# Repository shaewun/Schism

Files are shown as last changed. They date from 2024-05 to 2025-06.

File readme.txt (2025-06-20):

Shield: [][cc-by-nc-sa]

This work is licensed under a
[Creative Commons Attribution-NonCommercial-ShareAlike 4.0 International License][cc-by-nc-sa].

[][cc-by-nc-sa]

[cc-by-nc-sa]: http://creativecommons.org/licenses/by-nc-sa/4.0/
[cc-by-nc-sa-image]: https://licensebuttons.net/l/by-nc-sa/4.0/88x31.png
[cc-by-nc-sa-shield]: https://img.shields.io/badge/License-CC%20BY--NC--SA%204.0-lightgrey.svg

Featured Components
-------------------
Kailh hot swap PCB modules
Raspberry Pi Pico
Gateron Clear Switches (35g)
Injection Molded Bjart Keycaps
USBC interconnected adjustable modules
USBC-GCC cable 

Construction
------------
The Schism utilizes 3 pieces of CNC cut and bent metal, assembled with stainless steel screws, nylon knobs, and nylon washers to protect your controllers finish.

The Modules utilize an open frame design, with a threaded bottom plate. Each module is secured in place using powerful neodymium magnets. This allows you to make adjustments on the fly, while not having to worry about your controller coming apart in transit or moving during the heat of battle!

Repairability
-------------
The controllers boards are sold as a set for replacement, and are open sourced. The modules themselves are also open source and made readily available for emergency replacement. Everything can be replaced with a SINGLE hex key :)

Functionality
-------------
The lowest possible latency and max compatibility is ensured in console and USB modes with the 133Mhz ARM Cortex processor found in the Raspberry Pi Pico.

Support for Gamecube, Switch, and PC are built in. Further console functionality can be enabled using a Brooks Wingman USB stick for consoles like PS4 and new Xboxes.

Guides for this Wingman functionality will be made available in the future, in the mean time feel free to reach out for support or reassurance in setting up additional console functionality, its very easy and straightforward. There are also members of the Discord who are always glad to help.

Ergonomic Benefits
------------------
The Schism represents a new generation of ergonomics for digital fight pad users.

Based on the b0xx layout by Hax$, the schism re-engineers the locations, angles, and spacing of the right and left action clusters. They are rotated distally along the roll axis, this eliminates the need for ulnar deviation and forearm pronation, two of the most common postural causes of RSI (repetitive stress injuries).

Additionally, the personalized spacing and relative position of the modules allows users to relax their fingers into a natural curled position; this further reduces strain, and helps improve reaction times. The close spacing and mixed keycap choices allows the entire thumb to activate the 5 button action cluster with minimal movement and while maintaining optimum posture.

The Schism provides a superior ergonomic experience to traditional flat digital fight-pads or “rectangles”. Ask any of our many satisfied customers on the Discord or look at our reviews to see what has everyone talking!

Or just take it from some of Melee’s best digital players and WunVzn team members; Chef, Swift, and Joey Donuts.

If you have any questions my DMs and email shae@wunvzn.com are always open!

Plate Materials
---------------
The "surround" plates are made of one clear and one colored piece of 3mm acrylic.

The "bottom" plates are 1.5mm G50 galvanized steel and use m3x0.5mm threaded holes

The switch plates are recommended to be aluminum for the weight, but G50 can be cheaper and other materials may be preffered/substituted

All of these parts are ordered through sendcutsend

Hardware
--------
m3x20mm screws are used to hold everything together, these are inserted and threaded 1.5mm into the bottom once all the parts are stacked

8.5 inch 1/4 20 bolts are used to link the wings to the base of the shell

Nylon washers are set between the wings and base

Neoprene and metal washers are used on the outside to separate the nylon locking nuts and 1/4 20 bolt ends from the shell

the "Delta Clips" are introduced lastly, creating tension in the stack and separating the parts.

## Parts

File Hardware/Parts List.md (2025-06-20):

[8.5 inch 1/4 20 main bolts](https://www.mcmaster.com/92198A572/)

[m3x20 hex bolts](https://www.amazon.com/dp/B01EYA5DQW?ref_=ppx_hzsearch_conn_dt_b_fed_asin_title_1&th=1)

[Neoprene Sealing Washers](https://www.amazon.com/dp/B01N49WA60?ref_=ppx_hzsearch_conn_dt_b_fed_asin_title_3&th=1)

[Nylon Washers](https://www.amazon.com/dp/B009OLNI00?ref_=ppx_hzsearch_conn_dt_b_fed_asin_title_4)

[35g Gateron Clear](https://www.amazon.com/dp/B07CVRCSJM?ref_=ppx_hzsearch_conn_dt_b_fed_asin_title_1&th=1)

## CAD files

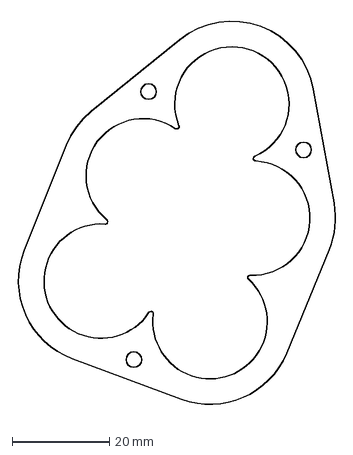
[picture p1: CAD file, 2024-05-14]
Modules/Action Module/SurroundAction.dxf
65.9 x 81.9 mm

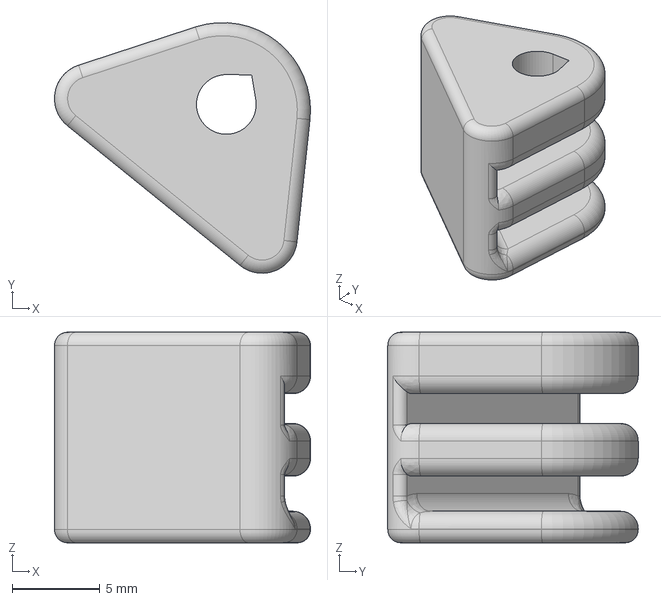
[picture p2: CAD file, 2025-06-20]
Modules/DeltaSpacer.step
14.6 x 14.3 x 12.0 mm

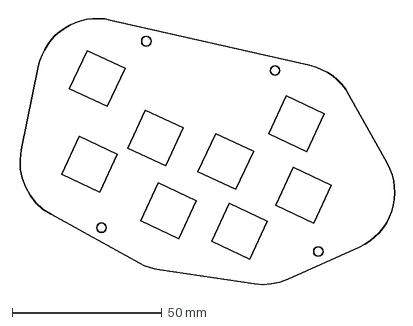
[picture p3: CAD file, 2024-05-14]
Modules/Home Module/SwitchPlateHome.dxf
127.2 x 89.9 mm

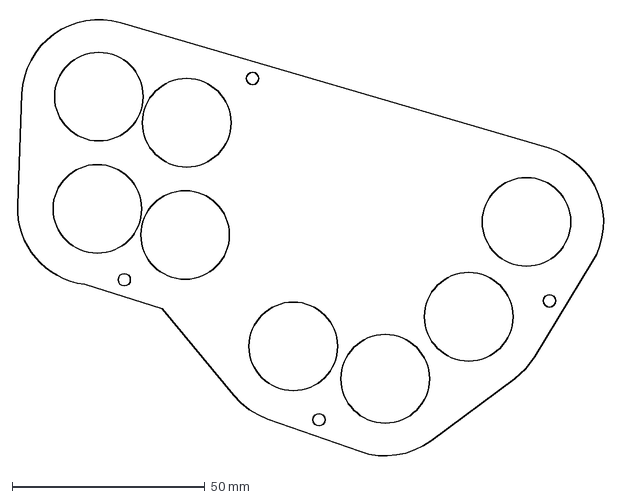
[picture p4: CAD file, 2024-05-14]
Modules/Left Module/SurroundLeft.dxf
153.4 x 115.2 mm

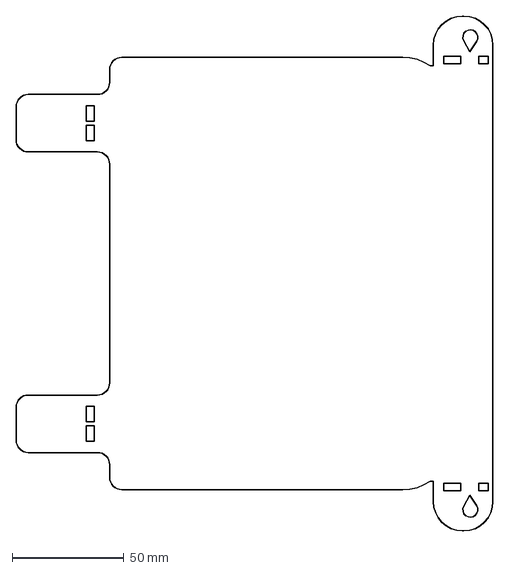
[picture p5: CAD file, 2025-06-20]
Shell/FLAPHANDBEND (1).dxf
213.4 x 230.3 mm

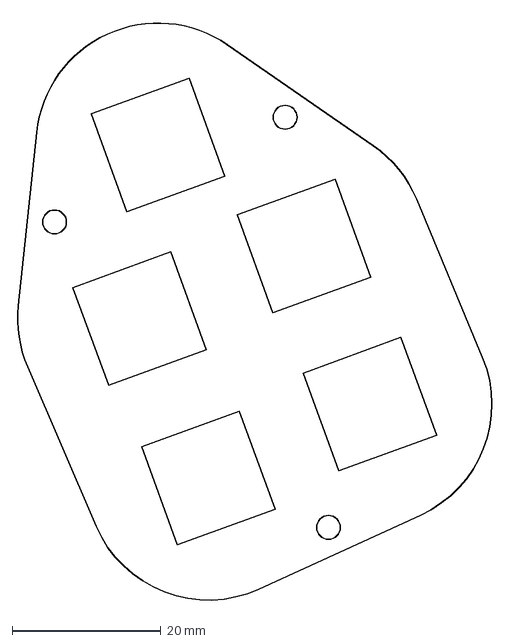
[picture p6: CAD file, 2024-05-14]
Modules/Action Module/SwitchPlateAction.dxf
66.1 x 79.0 mm

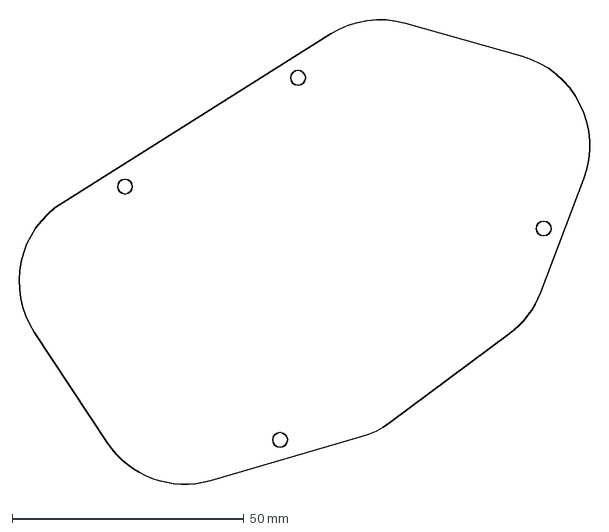
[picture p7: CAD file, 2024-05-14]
Modules/Home Module/BottomHome.dxf
124.4 x 102.6 mm

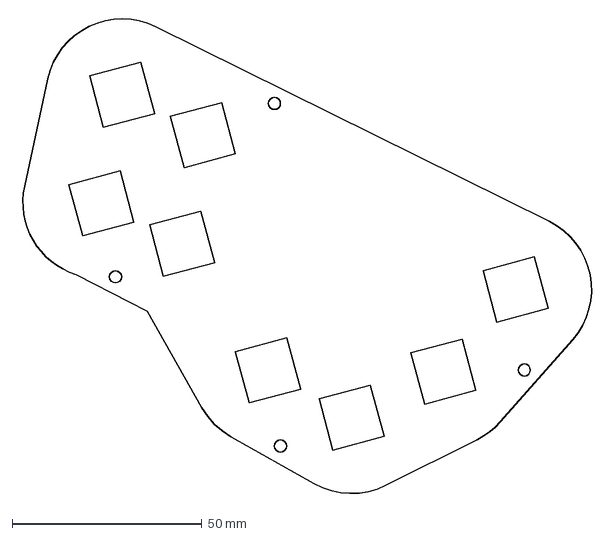
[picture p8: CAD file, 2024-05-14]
Modules/Left Module/SwitchPlateLeft.dxf
152.3 x 126.6 mm

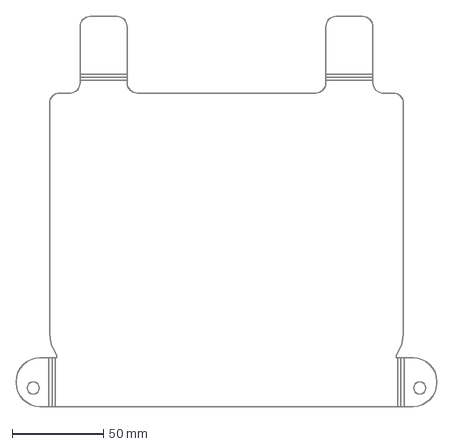
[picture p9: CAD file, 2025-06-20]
Shell/wing1 (1).dxf
230.3 x 213.4 mm

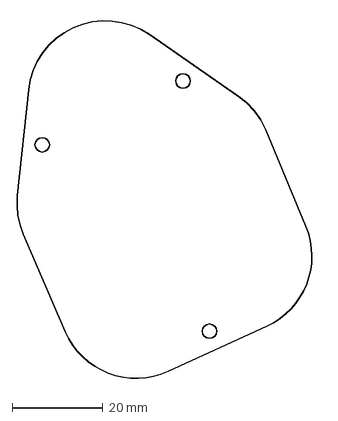
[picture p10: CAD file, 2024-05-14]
Modules/Action Module/BottomActionModule.dxf
67.4 x 80.2 mm

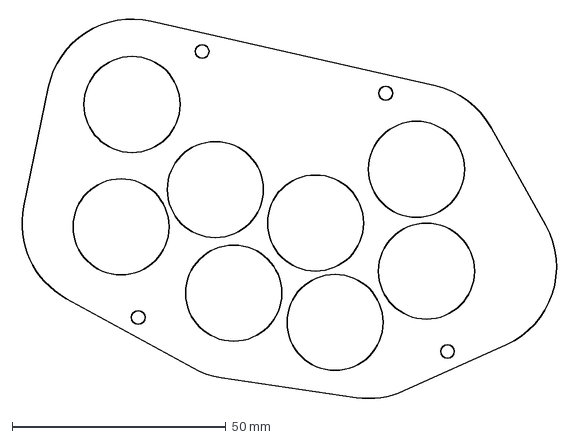
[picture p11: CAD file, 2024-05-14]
Modules/Home Module/SurroundHome.dxf
127.2 x 89.9 mm

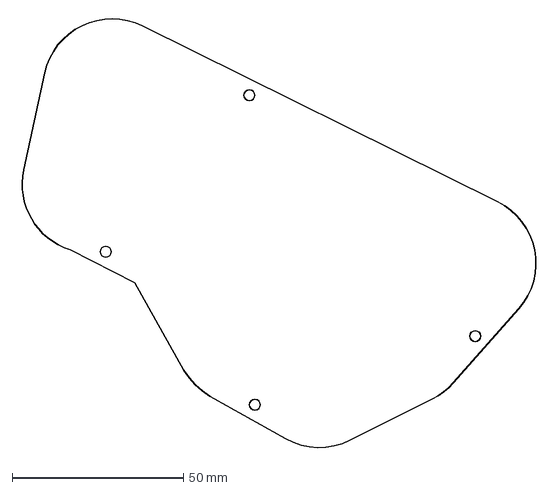
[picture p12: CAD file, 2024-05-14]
Modules/Left Module/BottomLeft.dxf
152.3 x 126.6 mm

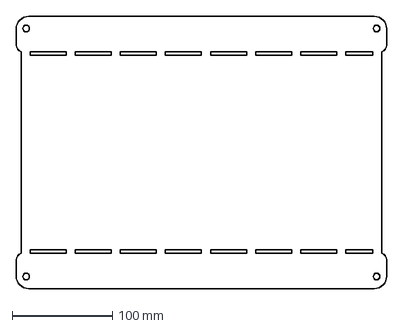
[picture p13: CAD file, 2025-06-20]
Shell/BASEHANDBEND (1).dxf
370.0 x 271.8 mm

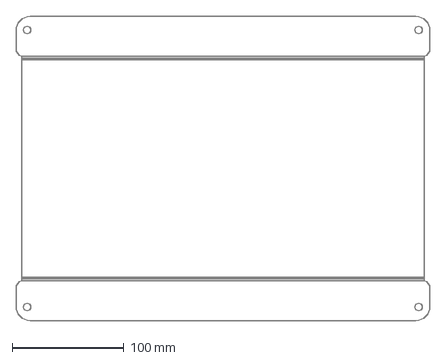
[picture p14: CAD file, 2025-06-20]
Shell/base1 (1).dxf
370.0 x 271.8 mm

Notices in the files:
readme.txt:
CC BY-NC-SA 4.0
